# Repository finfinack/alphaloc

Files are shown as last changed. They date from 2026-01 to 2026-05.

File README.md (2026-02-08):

# AlphaLoc

AlphaLoc is an ESP32 application that allows embedding GPS location data directly into Sony Alpha camera photos via Bluetooth Low Energy (BLE). It acts as a bridge between a standard GPS module and your Sony camera, providing real-time geolocation tagging.

## Features

- **Automatic Geotagging**: Sends GPS coordinates (Latitude, Longitude, Altitude, Time) to the camera.
- **BLE Connection**: Emulates a smartphone location provider for Sony cameras.
- **Dual Configuration**: Configurable via a Web Interface (WiFi) or BLE characteristics.
- **Status Indicators**: NeoPixel (RGB LED) feedback for Camera connection, GPS fix, Battery, and WiFi status.
- **Low Power**: Supports disabling external peripherals (like Stemma QT) to save power.

## Hardware Support

The project is set up for **PlatformIO** and currently supports:

| Board | Environment | Pinout |
|---|---|---|
| [**DFRobot Beetle ESP32-C6**](https://wiki.dfrobot.com/SKU_DFR1117_Beetle_ESP32_C6) | `esp32c6` | GPS TX: 5, GPS RX: 4, NeoPixel: 6 |
| [**Adafruit Feather ESP32-S3**](https://learn.adafruit.com/adafruit-esp32-s3-feather/overview)| `esp32s3` | GPS TX: 38, GPS RX: 39, NeoPixel: 6 |

You can easily adapt it to other ESP32 boards by modifying `platformio.ini`.

### Parts List

The following is a parts list of what I ended up with.

- [Adafruit ESP32-S3 Feather](https://www.adafruit.com/product/5885), [Overview](https://learn.adafruit.com/adafruit-esp32-s3-feather/overview)
- [Adafruit Ultimate GPS featherwing](https://learn.adafruit.com/adafruit-ultimate-gps-featherwing)
- [SparkFun RGB LED Breakout - WS2812B](https://www.sparkfun.com/sparkfun-rgb-led-breakout-ws2812b.html)
- [Adafruit WiFi Antenna with w.FL / MHF3 / IPEX3 Connector](https://www.adafruit.com/product/5445)
    - This is optional if you don't have an ESP32 with a PCB antenna.
- Mini sliding switch (8.5mm x 3.7mm, 3 pin, slider 4mm tall)
- The antenna of a GY-GPS6MV2
- 2x Panasonic NCR18650GA Battery (3450mAh)
- Wires, electrical tape and whatnot

### Models

- [**Holder**](model/holder.3mf): Holder for the batteries, ESP32, optional wifi antenna, ...
- [**Cover**](model/cover.3mf): Cover with a press fit for the holder and room for the LED board.
- [**Cover Large**](model/cover_large.3mf): Same as cover but taller and with room for a larger, external GPS antenna.

## Usage

### 1. Initial Setup

1. Connect your GPS module (e.g., GY-GPS6MV2 or an Adafruit Ultimate GPS Featherwing) to the defined TX/RX pins.

2. Flash the firmware using PlatformIO.

   ```bash
   pio run -e esp32c6 -t upload
   ```

3. Power on the device.

### 2. Pairing with Camera

1. On your Sony Alpha camera, go to **Network** -> **Bluetooth Settings**.
2. Enable **Bluetooth Function**.
3. Select **Pairing**.
4. The camera should discover "AlphaLoc". Select it to pair.
5. Once paired, go to **Location Info. Link Set.** and enable it.
6. The camera should now show the GPS icon (solid when receiving data).

### 3. LED Status Codes

The NeoPixel LED provides a visual "heartbeat" every 5 seconds. It flashes multiple colors in sequence to report the status of different subsystems:

**Sequence:** [Camera Status] -> [GPS Status] -> [Battery Status] -> [WiFi Status] -> [Sleep]

1.  **First Flash: Camera Connection**
    *   🟢 **Green**: Connected to camera and bonded.
    *   🔵 **Blue**: Connected to camera but not bonded yet.
    *   🔴 **Red**: Not connected.
2.  **Second Flash: GPS Fix**
    *   🟢 **Green**: Valid 3D GPS Fix acquired.
    *   🟣 **Violet**: *Fake* GPS fix (injected when `ALPHALOC_FAKE_GPS=1`).
    *   🔴 **Red**: No fix (searching for satellites).
3.  **Third Flash: Battery Level (Optional)**
    *   🟢 **Green**: > 50%
    *   🟡 **Yellow**: > 30%
    *   🔴 **Red**: <= 30%
4.  **Fourth Flash: WiFi/Config (Optional)**
    *   Only appears during the startup "Config Window" (first 5 minutes).
    *   🔵 **Blue**: Web server is active.
    *   ⚫ **(Off)**: Config window closed, WiFi disabled to save power.

**Example**:
*   🔴-🔴-🟢-🔵: No camera, no GPS, battery good, config mode active (just turned on).
*   🔵-🟢-🟡-⚫: Camera connected (not bonded yet), GPS fixed, battery medium, normal operation (config closed).
*   🟢-🟢-🔴-⚫: Camera connected (bonded), GPS fixed, battery low, normal operation (config closed).
*   🔵-🟣-🟢-⚫: Camera connected (not bonded yet), fake GPS fixed, battery good, normal operation (config closed).

### 4. Configuration

> **⚠️ SECURITY WARNING**: The BLE configuration service is **DISABLED by default** for security reasons. When enabled, it allows **UNAUTHENTICATED access** to device settings including WiFi passwords. Only enable it (`ALPHALOC_BLE_CONFIG=1`) in trusted environments or for initial setup, then rebuild with it disabled.

On startup, AlphaLoc enters a **Configuration Window** (default 5 minutes). During this time, you can change settings via WiFi (if `ALPHALOC_WIFI_WEB=1`) or BLE (if `ALPHALOC_BLE_CONFIG=1`).

web

#### Configuration Parameters

| Parameter | Description | Default |
|---|---|---|
| **Camera Name Prefix** | Filter which cameras to connect to. Useful if you have multiple Sonys. | `SonyA7` |
| **Camera MAC Prefix** | Connect only to a specific MAC address prefix. Empty matches any. | (Empty) |
| **TZ Offset** | Timezone offset in minutes (e.g., `60` for UTC+1). | `60` |
| **DST Offset** | Daylight Savings Time offset in minutes. | `60` |
| **WiFi SSID/Pass** | Credentials for connecting to your home WiFi. | `WiFi` / `changeme` |
| **AP SSID/Pass** | Credentials for the hotspot created by AlphaLoc. | `AlphaLoc` / `alphaloc1234` |
| **Max GPS Age** | How long (seconds) to reuse old coordinates if GPS signal is lost. | `300` |

#### Method A: WiFi Web Interface

AlphaLoc tries to connect to the configured WiFi as a client:

- **Default SSID**: `WiFi`
- **Default Password**: `changeme`
- **IP**: assigned via DHCP

If it can't connect to the WiFi, it starts an access point itself:

- **SSID**: `AlphaLoc`
- **Password**: `alphaloc1234`
- **IP**: `192.168.4.1` (direct link to webserver: http://192.168.4.1/)

To enable this, set the build flag (`ALPHALOC_WIFI_WEB=1` in `platformio.ini`).

#### Method B: BLE Configuration

You can use a generic BLE app (like nRF Connect) to write to the configuration service.

**Service UUID**: `B1F0B4D5-797B-5A9E-5B4F-4A1F01007EA1`

| Characteristic Name | UUID (Base `B1F0...`) | R/W | Type (Over BLE) | Description |
| --- | --- | --- | --- | --- |
| Camera Name Prefix  | `...02007EA1` | R/W | String | Camera name identifier |
| Camera MAC Prefix | `...03007EA1` | R/W | String | MAC address filter |
| Timezone Offset | `...04007EA1` | R/W | String (Int) | Minutes from UTC |
| DST Offset | `...05007EA1` | R/W | String (Int) | Daylight Savings offset (minutes) |
| Wifi SSID | `...07007EA1` | R/W | String | Station SSID |
| Wifi Password | `...08007EA1` | R/W | String | Station Password |
| AP SSID | `...09007EA1` | R/W | String | Access Point SSID |
| AP Password | `...0A007EA1` | R/W | String | Access Point Password |
| Max GPS Age | `...0B007EA1` | R/W | String (Int) | Max age of GPS lock in seconds |
| GPS Lock | `...0C007EA1` | R | String (0/1) | 1 when GPS lock is valid |
| GPS Satellites | `...0D007EA1` | R | String (Int) | Satellites in view (from GGA) |
| GPS Constellations  | `...0E007EA1` | R | String (Int) | Bitmask: 1=GPS, 2=GLONASS |
| Camera Connected | `...0F007EA1` | R | String (0/1) | BLE camera link active |
| Camera Bonded | `...10007EA1` | R | String (0/1) | Link bonded (after pairing) |

#### Build-Time Secrets (Recommended)

If you want to keep WiFi credentials and camera filters out of git, place them in `platformio.secrets.ini` and keep the file ignored. The build merges these flags into every environment via `platformio.ini`.

Example `platformio.secrets.ini` with all supported defaults:

```ini
[secrets]
build_flags =
  -DALPHALOC_DEFAULT_WIFI_SSID="\"MyWifi\""
  -DALPHALOC_DEFAULT_WIFI_PASS="\"MyPass\""
  -DALPHALOC_DEFAULT_AP_SSID="\"AlphaLoc\""
  -DALPHALOC_DEFAULT_AP_PASS="\"AlphaLocPass\""
  -DALPHALOC_DEFAULT_CAMERA_NAME_PREFIX="\"SonyA7\""
  -DALPHALOC_DEFAULT_CAMERA_MAC_PREFIX="\"AA:BB:CC\""
```

These values are used as defaults on first boot (or after a factory reset) and can still be changed later via the WiFi or BLE config UIs.

## BLE Client Details (Camera Link)

AlphaLoc acts as a BLE client to Sony cameras

### Advertisement Filters

- **Manufacturer data**: company ID `0x012D`, product ID `0x0003`
- **Optional name prefix filter**: `camera_name_prefix` (if set)
- **Optional MAC prefix filter**: `camera_mac_prefix` (if set)

### Services and Identifiers

AlphaLoc looks for two Sony services (UUIDs are built from 16-bit IDs using the Sony base UUID):

```
Sony base UUID (constructed):
  00000000-0000-8000-ffff-ffff-ffff-ffff
  with 16-bit words inserted at positions:
    first = 0xDD00 / 0xFF00
    second = 0xDD00 / 0xFF00
```

It accepts either 128-bit UUIDs or 16-bit UUIDs:

- **Location Service**: `0xDD00`
- **Remote Service**: `0xFF00`

### Characteristic Discovery

Within those services, AlphaLoc searches for:

**Location Service (DD00)**

- `0xDD21`: Flags read to determine if TZ/DST are required
- `0xDD30`: Lock location (0x00 - Off, 0x01 - On)
- `0xDD31`: Enable location updates (0x00 - Off, 0x01 - On)
- `0xDD11`: Location write characteristic; used for sending GPS payloads

Data is a 95 byte buffer

| Offset | Description | Remark |
|---|---|---|
| [0:1] | Payload Length (exclude these two bytes) | 0x5D = 93 bytes |
| [2:4] | Fixed Data | 0x0802FC |
| [5] | Flag of transmitting timezone offset and DST offset required | 0x03 for transmit and 0x00 for do not transmit |
| [6:10] | Fixed Data | 0x0000101010 |
| [11:14] | Latitude (multiplied by 10000000) | 0x0BF79E5E = 200777310 / 10000000 = 20.077731 |
| [15:18] | Longitude (multiplied by 10000000) 	 | 0x41C385A7 = 1103332775 / 10000000 = 110.3332775 |
| [19:20] | 	UTC Year | 0x07E4 = 2020 |
| [21] | 	UTC Month | 0x0B = 11 |
| [22] | 	UTC Day | 0x05 = 5 |
| [23] | 	UTC Hour | 0x04 = 4 |
| [24] | 	UTC Minute | 0x02 = 2 |
| [25] | 	UTC Second | 0x2A = 42 |
| [26:90] | 	Zeros  	 | 0x00 |
| *[91:92]  | 	Difference between UTC and current timezone in minutes | 0x01E0 = 480min = 8h (UTC+8) |
| *[93:94]  | 	Difference for DST in current timezone in minutes | |

**Remote Service (FF00)**

- `0xFF02` (notification characteristic; CCCD `0x2902`)

### Connection/Discovery Flow (simplified)

```
ADV (Sony) --> connect
  |
  +--> discover DD00 (Location Service)
  |      +--> find DD11, DD21, DD30, DD31
  |      +--> read DD21 flag byte
  |      +--> enable location writes on DD11
  |
  +--> discover FF00 (Remote Service)
         +--> find FF02
         +--> find/guess CCCD (0x2902)
         +--> enable notifications
```

### Sending Location

Once services and characteristics are resolved:
- Builds a Sony-compatible location payload
- Writes to `DD11`
- Enables FF02 notifications after first location write (if required)

## Configuration Options

- **Camera Name Prefix**: Limits connection to cameras starting with this name (Default: "SonyA7").
- **Timezone/DST**: Offset in minutes for timestamp correction.
- **Max GPS Age**: How long to keep sending the last known location if GPS signal is lost.

## Building

This project uses the Espressif IoT Development Framework (ESP-IDF) within PlatformIO.
Check `platformio.ini` for build flags and pin definitions.

```ini
; Example Override
build_flags =
  -DGPS_UART_TX_PIN=5
  -DGPS_UART_RX_PIN=4
```

### Build Environments

The `platformio.ini` file defines several build environments for different purposes:

*   **`env:esp32c6`**: The standard production build for the ESP32-C6. Logging is disabled for performance.
*   **`env:esp32c6-debug`**: A debugging environment.
    *   Enables verbose logging (`ALPHALOC_VERBOSE=1`).
    *   **Enables Fake GPS (`ALPHALOC_FAKE_GPS=1`)**: Simulates a stationary location (Munich) for testing without a GPS module or satellite lock.
*   **`env:esp32c6-debug-gps`**: Debugging environment using *real* GPS data but with verbose logging enabled.
*   **`env:esp32s3`**: The standard production build for the ESP32-S3. Logging is disabled for performance.
*   **`env:esp32s3-debug`**: A debugging environment.
    *   Enables verbose logging (`ALPHALOC_VERBOSE=1`).
    *   **Enables Fake GPS (`ALPHALOC_FAKE_GPS=1`)**: Simulates a stationary location (Munich) for testing without a GPS module or satellite lock.
*   **`env:esp32s3-debug-gps`**: Debugging environment using *real* GPS data but with verbose logging enabled.

### Build Flags

You can customize the firmware behavior using these compilation flags in `platformio.ini`:

| Flag | Description | Default |
|---|---|---|
| `ALPHALOC_WIFI_WEB` | Enable internal settings web server. Set to `0` to remove WiFi stack and save power/flash. | `1` |
| `ALPHALOC_BLE_CONFIG` | **Enable BLE configuration service.** Note: This allows reading and writing the config via BLE unauthenticated! | `0` (DISABLED) |
| `ALPHALOC_VERBOSE` | Enable extensive debug logging to serial UART. | `0` |
| `ALPHALOC_FAKE_GPS` | Ignore UART GPS and output a static test location. | `0` |
| `ALPHALOC_NEOPIXEL_PIN`| GPIO pin number for the WS2812B NeoPixel. | (Board dependent) |
| `ALPHALOC_BATTERY_MONITOR` | Enable MAX17048 / LC709203F battery monitor over I2C. | `0` |
| `ALPHALOC_BATTERY_SDA_PIN` | I2C SDA pin for battery monitor. | (Board dependent) |
| `ALPHALOC_BATTERY_SCL_PIN` | I2C SCL pin for battery monitor. | (Board dependent) |
| `ALPHALOC_BATTERY_I2C_POWER_PIN` | Optional power-enable pin for I2C battery monitor. | (Unset) |
| `GPS_UART_TX_PIN` | TX Pin for GPS Serial (Connects to GPS RX). | (Board dependent) |
| `GPS_UART_RX_PIN` | RX Pin for GPS Serial (Connects to GPS TX). | (Board dependent) |
| `DALPHALOC_FACTORY_RESET` | If set to `1`, wipes NVS settings on boot. Dangerous. | Undefined |

**Security Best Practices:**
- Keep `ALPHALOC_BLE_CONFIG=0` in production builds
- Only enable BLE config for initial setup in controlled environments
- Use WiFi config (`ALPHALOC_WIFI_WEB=1`) with strong AP password instead
- Change default WiFi credentials immediately after first boot

## References

There is a bunch of work done by others before me which greatly helped figuring out how the BLE protocol works with the Sony Alpha cameras. I'm sure I'm forgetting a bunch but to at least name a few:

- https://github.com/dzwiedziu-nkg/esp32-a7iv-rc
- https://github.com/ekutner/camera-gps-link
- https://github.com/whc2001/ILCE7M3ExternalGps
- And many more (search GitHub for one of the unique identifiers such as the service UUIDs).

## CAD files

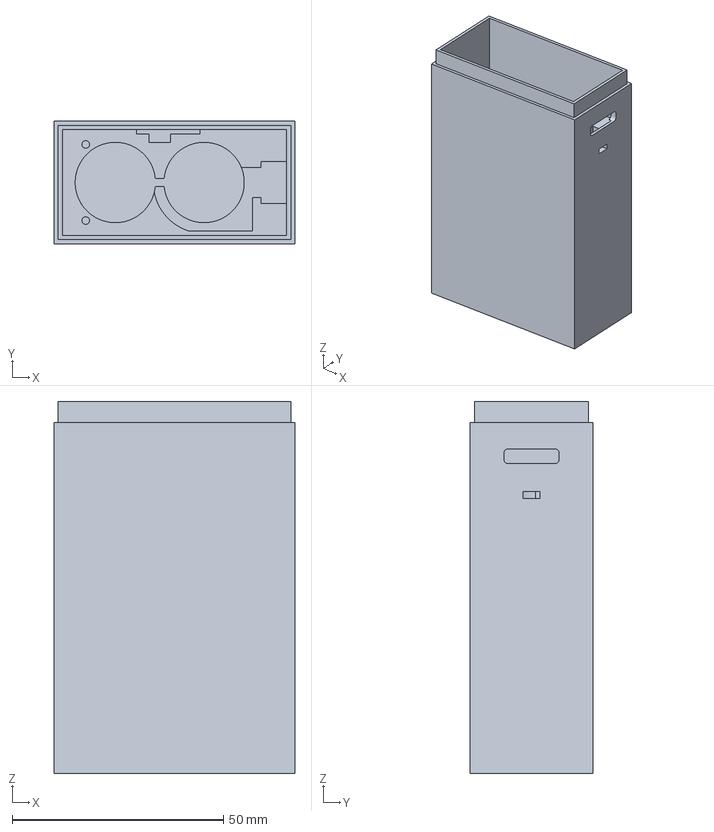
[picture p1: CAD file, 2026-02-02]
models/holder.3mf
57.0 x 29.0 x 88.0 mm

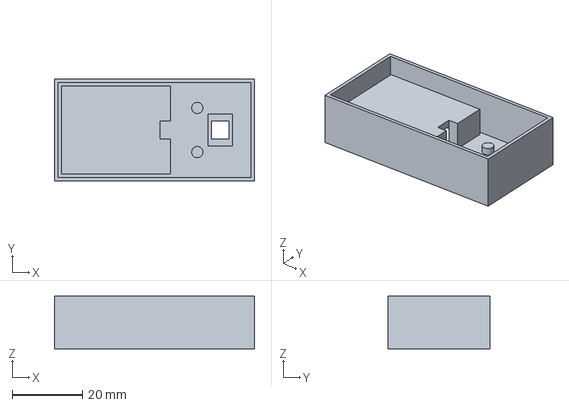
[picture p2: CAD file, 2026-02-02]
models/cover_large.3mf
57.0 x 29.0 x 15.0 mm

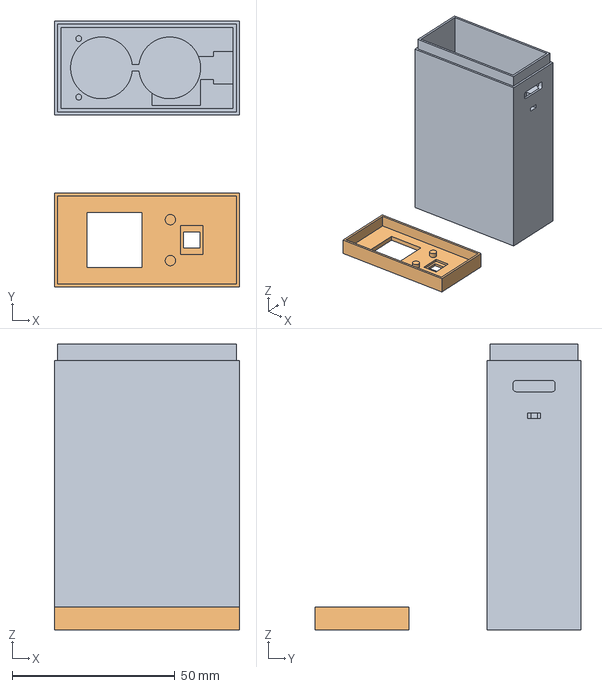
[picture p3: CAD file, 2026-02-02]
models/cover.3mf
57.0 x 82.0 x 88.0 mm

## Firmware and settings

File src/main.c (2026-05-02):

#include <string.h>

#include "ble_client.h"
#if ALPHALOC_BLE_CONFIG
#include "ble_config_server.h"
#endif
#include "config.h"
#include "driver/gpio.h"
#include "driver/uart.h"
#include "esp_err.h"
#include "esp_log.h"
#if CONFIG_PM_ENABLE
#include "esp_pm.h"
#endif
#include "esp_rom_sys.h"
#include "esp_timer.h"
#include "freertos/FreeRTOS.h"
#include "freertos/task.h"
#include "gps.h"
#include "nvs_flash.h"

#ifndef ALPHALOC_BATTERY_MONITOR
#define ALPHALOC_BATTERY_MONITOR 0
#endif

#if ALPHALOC_BATTERY_MONITOR
#include "battery.h"
#endif

#ifdef ALPHALOC_NEOPIXEL_PIN
#include "neopixel.h"
#endif

#ifndef ALPHALOC_WIFI_WEB
#define ALPHALOC_WIFI_WEB 1
#endif

#if ALPHALOC_WIFI_WEB
#include "wifi_web.h"
#endif

#define GPS_UART_NUM UART_NUM_1
#ifndef GPS_UART_TX_PIN
#error "GPS_UART_TX_PIN must be set via build_flags"
#endif
#ifndef GPS_UART_RX_PIN
#error "GPS_UART_RX_PIN must be set via build_flags"
#endif
#ifndef GPS_UART_BAUD
#define GPS_UART_BAUD 9600
#endif

#ifndef ALPHALOC_FAKE_GPS
#define ALPHALOC_FAKE_GPS 0
#endif

#ifndef ALPHALOC_LIGHT_SLEEP
#define ALPHALOC_LIGHT_SLEEP 0
#endif

#define FAKE_LAT_DEG 48.137154
#define FAKE_LON_DEG 11.576124
#define FAKE_YEAR 2024
#define FAKE_MONTH 1
#define FAKE_DAY 1
#define FAKE_HOUR 12
#define FAKE_MINUTE 0
#define FAKE_SECOND 0

static const char *TAG = "main";
static app_config_t s_cfg;
static int64_t s_config_window_end_time_us = 0;

static bool get_location_for_send(gps_fix_t *out_fix) {
  gps_fix_t fix;
  if (gps_get_latest(&fix) && fix.valid) {
    *out_fix = fix;
    return true;
  }
#if ALPHALOC_FAKE_GPS
  memset(&fix, 0, sizeof(fix));
  fix.lat_deg = FAKE_LAT_DEG;
  fix.lon_deg = FAKE_LON_DEG;
  fix.valid = true;
  fix.time_valid = true;
  fix.year = FAKE_YEAR;
  fix.month = FAKE_MONTH;
  fix.day = FAKE_DAY;
  fix.hour = FAKE_HOUR;
  fix.minute = FAKE_MINUTE;
  fix.second = FAKE_SECOND;
  fix.last_fix_time_us = esp_timer_get_time();
  fix.last_update_time_us = fix.last_fix_time_us;
  *out_fix = fix;
  return true;
#else
  return false;
#endif
}

static void focus_update_cb(void *ctx) {
  app_config_t *cfg = (app_config_t *)ctx;
  app_config_t cfg_snapshot;
  if (!config_get_snapshot(cfg, &cfg_snapshot)) {
    cfg_snapshot = *cfg;
    config_validate(&cfg_snapshot);
  }
  gps_fix_t fix;
  if (!get_location_for_send(&fix)) {
    return;
  }
  int64_t now = esp_timer_get_time();
  if ((now - fix.last_fix_time_us) >
      (int64_t)cfg_snapshot.max_gps_age_s * 1000000LL) {
    return;
  }
  ble_client_send_location(&fix);
}

static void location_publisher_task(void *arg) {
  const app_config_t *cfg = (const app_config_t *)arg;
  while (true) {
    app_config_t cfg_snapshot;
    if (!config_get_snapshot(cfg, &cfg_snapshot)) {
      cfg_snapshot = *cfg;
      config_validate(&cfg_snapshot);
    }
    gps_fix_t fix;
    if (get_location_for_send(&fix)) {
      int64_t now = esp_timer_get_time();
      if ((now - fix.last_fix_time_us) <=
          (int64_t)cfg_snapshot.max_gps_age_s * 1000000LL) {
        ble_client_send_location(&fix);
      }
    }
    vTaskDelay(pdMS_TO_TICKS(cfg_snapshot.gps_interval_ms));
  }
}

static void config_window_task(void *arg) {
  app_config_t *cfg = (app_config_t *)arg;
  app_config_t cfg_snapshot;
  if (!config_get_snapshot(cfg, &cfg_snapshot)) {
    cfg_snapshot = *cfg;
    config_validate(&cfg_snapshot);
  }
#if ALPHALOC_BLE_CONFIG
  ble_config_server_start();
#endif
#if ALPHALOC_WIFI_WEB
  wifi_web_start(cfg);
#endif
  s_config_window_end_time_us =
      esp_timer_get_time() + ((int64_t)cfg_snapshot.config_window_s * 1000000LL);
  vTaskDelay(pdMS_TO_TICKS(cfg_snapshot.config_window_s * 1000ULL));
#if ALPHALOC_BLE_CONFIG
  ble_config_server_stop();
#endif
#if ALPHALOC_WIFI_WEB
  wifi_web_stop();
#endif
  vTaskDelete(NULL);
}

#if ALPHALOC_BATTERY_MONITOR
static void battery_task(void *arg) {
  (void)arg;
  battery_read_now();
  while (true) {
    vTaskDelay(pdMS_TO_TICKS(60000));
    battery_read_now();
  }
}
#endif

#ifdef ALPHALOC_NEOPIXEL_PIN
static void status_led_task(void *arg) {
  (void)arg;
  const uint8_t brightness = 8;
  const TickType_t on_ms = pdMS_TO_TICKS(150);
  const TickType_t off_ms = pdMS_TO_TICKS(150);
  const TickType_t cycle_ms = pdMS_TO_TICKS(5000);

  neopixel_init(ALPHALOC_NEOPIXEL_PIN, brightness);

  while (true) {
    TickType_t cycle_start = xTaskGetTickCount();

    // Camera status: green if connected and bonded, blue if connected only, red
    // if not connected.
    bool camera_connected = ble_client_is_connected();
    bool camera_bonded = ble_client_is_bonded();
    if (camera_connected && camera_bonded) {
      neopixel_set_rgb(0, 255, 0);
    } else if (camera_connected) {
      neopixel_set_rgb(0, 0, 255);
    } else {
      neopixel_set_rgb(255, 0, 0);
    }
    vTaskDelay(on_ms);
    neopixel_set_rgb(0, 0, 0);
    vTaskDelay(off_ms);

    // GPS status: green if fix is valid, red if not. Fake GPS shows violet.
    gps_fix_t fix;
    bool gps_ok = gps_get_latest(&fix) && fix.valid;
    if (gps_ok) {
#if ALPHALOC_FAKE_GPS
      neopixel_set_rgb(128, 0, 255);
#else
      neopixel_set_rgb(0, 255, 0);
#endif
    } else {
      neopixel_set_rgb(255, 0, 0);
    }
    vTaskDelay(on_ms);
    neopixel_set_rgb(0, 0, 0);
    vTaskDelay(off_ms);

    // Battery status: green >50%, yellow >30%, red otherwise (if enabled).
#if ALPHALOC_BATTERY_MONITOR
    battery_status_t bat = {0};
    if (battery_get_status(&bat) && bat.valid) {
      if (bat.percent > 50.0f) {
        neopixel_set_rgb(0, 255, 0);
      } else if (bat.percent > 30.0f) {
        neopixel_set_rgb(255, 180, 0);
      } else {
        neopixel_set_rgb(255, 0, 0);
      }
      vTaskDelay(on_ms);
      neopixel_set_rgb(0, 0, 0);
      vTaskDelay(off_ms);
    }
#endif

    // Wi-Fi status: blue if web server/AP active.
#if ALPHALOC_WIFI_WEB
    int64_t now = esp_timer_get_time();
    bool window_active =
        (s_config_window_end_time_us == 0 || now < s_config_window_end_time_us);
    if (window_active) {
      neopixel_set_rgb(0, 0, 255);
      vTaskDelay(on_ms);
      neopixel_set_rgb(0, 0, 0);
      vTaskDelay(off_ms);
    }
#endif

    TickType_t elapsed = xTaskGetTickCount() - cycle_start;
    if (elapsed < cycle_ms) {
      vTaskDelay(cycle_ms - elapsed);
    }
  }
}
#endif

void app_main(void) {
  ESP_LOGI(TAG, "AlphaLoc starting");

#if CONFIG_PM_ENABLE
  // Configure automatic light sleep (Issue 3.4)
  esp_pm_config_t pm_config = {
      .max_freq_mhz = 160,
      .min_freq_mhz = 40,
      .light_sleep_enable =
#if CONFIG_FREERTOS_USE_TICKLESS_IDLE && ALPHALOC_LIGHT_SLEEP
          true,
#else
          false,
#endif
  };
  esp_err_t pm_err = esp_pm_configure(&pm_config);
  if (pm_err == ESP_OK) {
    ESP_LOGI(TAG, "Power management: light sleep %s",
             pm_config.light_sleep_enable ? "enabled" : "disabled");
  } else {
    ESP_LOGW(TAG, "Power management configuration failed: %s",
             esp_err_to_name(pm_err));
  }
#if !ALPHALOC_LIGHT_SLEEP
  ESP_LOGI(TAG, "Automatic light sleep disabled for BLE camera reliability");
#elif !CONFIG_FREERTOS_USE_TICKLESS_IDLE
  ESP_LOGW(TAG, "Automatic light sleep disabled - enable "
                "CONFIG_FREERTOS_USE_TICKLESS_IDLE");
#endif
#else
  ESP_LOGW(TAG, "Power management disabled in sdkconfig - enable "
                "CONFIG_PM_ENABLE for light sleep");
#endif

#ifdef ALPHALOC_STEMMA_QT_DISABLE_PIN
  // Disable STEMMA QT power for lower power usage when unused.
  gpio_config_t stemma_cfg = {
      .pin_bit_mask = 1ULL << ALPHALOC_STEMMA_QT_DISABLE_PIN,
      .mode = GPIO_MODE_OUTPUT,
      .pull_up_en = GPIO_PULLUP_DISABLE,
      .pull_down_en = GPIO_PULLDOWN_DISABLE,
      .intr_type = GPIO_INTR_DISABLE,
  };
  ESP_ERROR_CHECK(gpio_config(&stemma_cfg));
  ESP_ERROR_CHECK(gpio_set_level(ALPHALOC_STEMMA_QT_DISABLE_PIN, 0));
#endif
  esp_err_t err = nvs_flash_init();
  if (err == ESP_ERR_NVS_NO_FREE_PAGES ||
      err == ESP_ERR_NVS_NEW_VERSION_FOUND) {
#ifdef ALPHALOC_FACTORY_RESET
    if (ALPHALOC_FACTORY_RESET) {
      ESP_ERROR_CHECK(nvs_flash_erase());
      ESP_ERROR_CHECK(nvs_flash_init());
    } else {
      ESP_LOGW(TAG, "NVS needs erase but factory reset disabled; keeping data");
    }
#else
    ESP_LOGW(TAG,
             "NVS needs erase but factory reset flag not set; keeping data");
#endif
  } else if (err != ESP_OK) {
    ESP_LOGE(TAG, "NVS init failed: %s", esp_err_to_name(err));
  }

  config_load(&s_cfg);
  config_validate(&s_cfg);

  gps_config_t gps_cfg = {
      .uart_num = GPS_UART_NUM,
      .tx_pin = GPS_UART_TX_PIN,
      .rx_pin = GPS_UART_RX_PIN,
      .baud_rate = GPS_UART_BAUD,
      .update_interval_ms = s_cfg.gps_interval_ms,
  };
  gps_init(&gps_cfg);

  ble_client_init(&s_cfg);
  ble_client_set_focus_callback(focus_update_cb, &s_cfg);

  BaseType_t ret;
#if ALPHALOC_BATTERY_MONITOR
  battery_init();
  ret = xTaskCreate(battery_task, "battery", 3072, NULL, 4, NULL);
  if (ret != pdPASS) {
    ESP_LOGE(TAG, "Failed to create battery_task");
  }
#endif
  ret = xTaskCreate(location_publisher_task, "location_pub", 4096, &s_cfg, 5,
                    NULL);
  if (ret != pdPASS) {
    ESP_LOGE(TAG, "Failed to create location_publisher_task");
  }

  if (s_cfg.config_window_s > 0) {
    ret =
        xTaskCreate(config_window_task, "config_window", 4096, &s_cfg, 5, NULL);
    if (ret != pdPASS) {
      ESP_LOGE(TAG, "Failed to create config_window_task");
    }
  }
#ifdef ALPHALOC_NEOPIXEL_PIN
  ret = xTaskCreate(status_led_task, "status_led", 3072, &s_cfg, 1, NULL);
  if (ret != pdPASS) {
    ESP_LOGE(TAG, "Failed to create status_led_task");
  }
#endif
  ESP_LOGI(TAG, "AlphaLoc started");
}

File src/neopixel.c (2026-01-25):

#include "neopixel.h"

#include <string.h>

#include "driver/rmt_encoder.h"
#include "driver/rmt_tx.h"
#include "esp_check.h"
#include "esp_log.h"
#include "freertos/FreeRTOS.h"
#include "freertos/task.h"

typedef struct {
  rmt_encoder_t base;
  rmt_encoder_t *bytes_encoder;
  rmt_encoder_t *copy_encoder;
  int state;
  rmt_symbol_word_t reset_code;
} rmt_led_strip_encoder_t;

static const char *TAG = "neopixel";
static rmt_channel_handle_t s_tx_chan;
static rmt_encoder_handle_t s_led_encoder;
static uint8_t s_brightness = 8;

static size_t rmt_encode_led_strip(rmt_encoder_t *encoder,
                                   rmt_channel_handle_t channel,
                                   const void *primary_data,
                                   size_t data_size,
                                   rmt_encode_state_t *ret_state) {
  rmt_led_strip_encoder_t *led_encoder = __containerof(encoder, rmt_led_strip_encoder_t, base);
  rmt_encode_state_t session_state = RMT_ENCODING_RESET;
  rmt_encode_state_t state = RMT_ENCODING_RESET;
  size_t encoded_symbols = 0;

  switch (led_encoder->state) {
    case 0:
      encoded_symbols += led_encoder->bytes_encoder->encode(
          led_encoder->bytes_encoder, channel, primary_data, data_size, &session_state);
      if (session_state & RMT_ENCODING_COMPLETE) {
        led_encoder->state = 1;
      }
      if (session_state & RMT_ENCODING_MEM_FULL) {
        state |= RMT_ENCODING_MEM_FULL;
        goto out;
      }
      // fall-through
    case 1:
      encoded_symbols += led_encoder->copy_encoder->encode(
          led_encoder->copy_encoder, channel, &led_encoder->reset_code,
          sizeof(led_encoder->reset_code), &session_state);
      if (session_state & RMT_ENCODING_COMPLETE) {
        led_encoder->state = RMT_ENCODING_RESET;
        state |= RMT_ENCODING_COMPLETE;
      }
      if (session_state & RMT_ENCODING_MEM_FULL) {
        state |= RMT_ENCODING_MEM_FULL;
        goto out;
      }
  }

out:
  *ret_state = state;
  return encoded_symbols;
}

static esp_err_t rmt_del_led_strip_encoder(rmt_encoder_t *encoder) {
  rmt_led_strip_encoder_t *led_encoder = __containerof(encoder, rmt_led_strip_encoder_t, base);
  if (led_encoder->bytes_encoder) {
    rmt_del_encoder(led_encoder->bytes_encoder);
  }
  if (led_encoder->copy_encoder) {
    rmt_del_encoder(led_encoder->copy_encoder);
  }
  free(led_encoder);
  return ESP_OK;
}

static esp_err_t rmt_led_strip_encoder_reset(rmt_encoder_t *encoder) {
  rmt_led_strip_encoder_t *led_encoder = __containerof(encoder, rmt_led_strip_encoder_t, base);
  rmt_encoder_reset(led_encoder->bytes_encoder);
  rmt_encoder_reset(led_encoder->copy_encoder);
  led_encoder->state = RMT_ENCODING_RESET;
  return ESP_OK;
}

static esp_err_t rmt_new_led_strip_encoder(uint32_t resolution_hz,
                                           rmt_encoder_handle_t *ret_encoder) {
  esp_err_t ret = ESP_OK;
  rmt_led_strip_encoder_t *led_encoder = NULL;
  ESP_GOTO_ON_FALSE(ret_encoder, ESP_ERR_INVALID_ARG, err, TAG, "invalid argument");
  led_encoder = rmt_alloc_encoder_mem(sizeof(rmt_led_strip_encoder_t));
  ESP_GOTO_ON_FALSE(led_encoder, ESP_ERR_NO_MEM, err, TAG, "no mem for encoder");
  led_encoder->base.encode = rmt_encode_led_strip;
  led_encoder->base.del = rmt_del_led_strip_encoder;
  led_encoder->base.reset = rmt_led_strip_encoder_reset;

  rmt_bytes_encoder_config_t bytes_encoder_config = {
      .bit0 = {
          .level0 = 1,
          .duration0 = 0.3 * resolution_hz / 1000000,
          .level1 = 0,
          .duration1 = 0.9 * resolution_hz / 1000000,
      },
      .bit1 = {
          .level0 = 1,
          .duration0 = 0.9 * resolution_hz / 1000000,
          .level1 = 0,
          .duration1 = 0.3 * resolution_hz / 1000000,
      },
      .flags.msb_first = 1,
  };
  ESP_GOTO_ON_ERROR(rmt_new_bytes_encoder(&bytes_encoder_config, &led_encoder->bytes_encoder), err,
                    TAG, "create bytes encoder failed");
  rmt_copy_encoder_config_t copy_encoder_config = {};
  ESP_GOTO_ON_ERROR(rmt_new_copy_encoder(&copy_encoder_config, &led_encoder->copy_encoder), err,
                    TAG, "create copy encoder failed");

  uint32_t reset_ticks = resolution_hz / 1000000 * 50 / 2;
  led_encoder->reset_code = (rmt_symbol_word_t){
      .level0 = 0,
      .duration0 = reset_ticks,
      .level1 = 0,
      .duration1 = reset_ticks,
  };
  *ret_encoder = &led_encoder->base;
  return ESP_OK;

err:
  if (led_encoder) {
    if (led_encoder->bytes_encoder) {
      rmt_del_encoder(led_encoder->bytes_encoder);
    }
    if (led_encoder->copy_encoder) {
      rmt_del_encoder(led_encoder->copy_encoder);
    }
    free(led_encoder);
  }
  return ret;
}

static void scale_rgb(uint8_t *r, uint8_t *g, uint8_t *b) {
  uint16_t scale = s_brightness;
  *r = (uint8_t)((*r * scale) / 255);
  *g = (uint8_t)((*g * scale) / 255);
  *b = (uint8_t)((*b * scale) / 255);
}

void neopixel_init(int gpio_pin, uint8_t brightness) {
  s_brightness = brightness;

  rmt_tx_channel_config_t tx_config = {
      .gpio_num = gpio_pin,
      .clk_src = RMT_CLK_SRC_DEFAULT,
      .resolution_hz = 10 * 1000 * 1000,
      .mem_block_symbols = 64,
      .trans_queue_depth = 1,
      .intr_priority = 0,
  };
  tx_config.flags.with_dma = 0;
  tx_config.flags.invert_out = 0;

  ESP_ERROR_CHECK(rmt_new_tx_channel(&tx_config, &s_tx_chan));
  ESP_ERROR_CHECK(rmt_new_led_strip_encoder(tx_config.resolution_hz, &s_led_encoder));
  ESP_ERROR_CHECK(rmt_enable(s_tx_chan));
}

void neopixel_set_rgb(uint8_t r, uint8_t g, uint8_t b) {
  if (!s_tx_chan || !s_led_encoder) {
    return;
  }
  scale_rgb(&r, &g, &b);
  uint8_t grb[3] = {g, r, b};
  rmt_transmit_config_t tx_cfg = {
      .loop_count = 0,
  };
  tx_cfg.flags.eot_level = 0;
  tx_cfg.flags.queue_nonblocking = 0;
  ESP_ERROR_CHECK(rmt_transmit(s_tx_chan, s_led_encoder, grb, sizeof(grb), &tx_cfg));
  ESP_ERROR_CHECK(rmt_tx_wait_all_done(s_tx_chan, 20));
}

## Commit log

2026-01-21 replace app with vibe coded working one
    [partitions.csv]
2026-01-22 add feather board target, make gps loc timeout configurable
    [partitions-c6.csv, partitions.csv]
2026-01-22 add feather board target
2026-01-23 feather fixing
    [partitions-feather.csv]
2026-01-23 make uart pins configurable per board
2026-01-25 avoid erasing flash unless specified
    [main.c]
2026-01-25 many fixes, exposing status and readme updates
    [gps.c, main.c]
2026-01-31 fix led for config window
    [main.c]
2026-01-31 fix minor logic flaws
    [gps.c, main.c]
2026-01-31 reduce power usage
2026-01-31 improve website, replace feather with s3, add nmea logging
    [partitions-feather.csv, partitions.csv]
2026-01-31 minor fixes, more platforms
    [gps.c, main.c]
2026-02-01 add release build target for esp32s3
2026-02-01 add battery monitoring
2026-02-02 add parts and 3d models
    [cover.3mf, cover_large.3mf, holder.3mf]
2026-05-02 bunch of fixes, power savings, BLE reconnect improvements, etc
    [battery.c, gps.c, main.c]
